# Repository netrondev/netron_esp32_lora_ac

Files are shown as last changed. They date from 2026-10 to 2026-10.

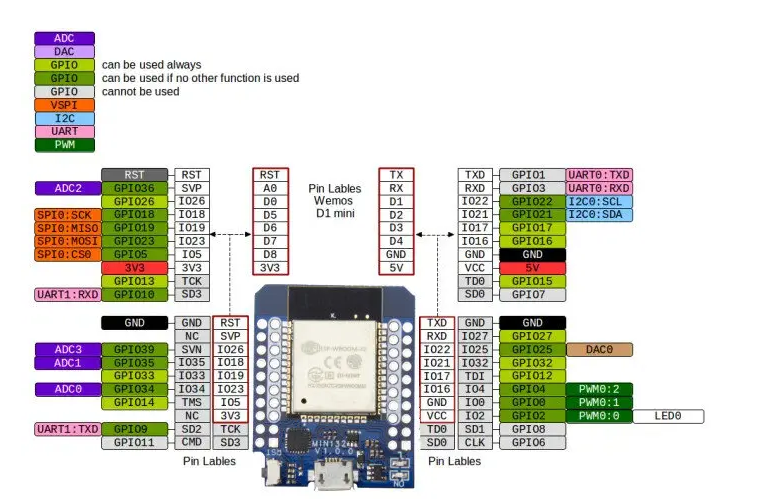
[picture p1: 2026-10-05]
images/esp32-mini-pinout.png

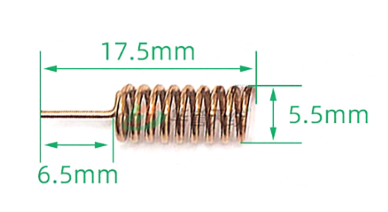
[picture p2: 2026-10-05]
hardware/antenna_868.png

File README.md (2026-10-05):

# ESP32 LoRaWAN AC current monitor

A mains current monitor built on an ESP32 and an SX1262 radio. It measures AC
current through an ACS712 hall-effect sensor and reports it over LoRaWAN as an
OTAA Class A device. The repo also includes a small network server so you can
receive the reports and configure devices remotely, plus the KiCad hardware.

Everything is written in Rust except the payload codec, which is plain
JavaScript so it can be pasted into ChirpStack, The Things Network or Node-RED.

## How the pieces fit together

```
ACS712 current sensor
  └─ ESP32 + SX1262           firmware/           OTAA Class A device
       ~ 868.1 MHz SF7 ~
  └─ Milesight UG63 gateway                       Semtech UDP packet forwarder
       └─ software/lorans                         network server: joins, keys,
                                                  uplink decode, downlink queue
```

The gateway's own network server is **not** used. It has no usable downlink
route: there's no HTTP endpoint, and its MQTT application forwarder reboots the
gateway. Without downlinks there's no remote configuration. So the gateway runs
as a plain packet forwarder, and `software/lorans` does the network server's
job. `software/lorans/README.md` has the details.

Any gateway that speaks the Semtech UDP protocol should work in place of the
UG63. Alternatively, the devices can join a standard network server such as
ChirpStack, using the codec in `software/loradecode`.

| Directory | What it is |
|---|---|
| `firmware/` | ESP32 firmware. Measures current, joins by OTAA, reports aggregated min/avg/max, applies configuration downlinks |
| `software/lorans/` | Network server. Run this to receive uplinks and send commands |
| `software/loradecode/` | JavaScript payload decoder and command encoder for ChirpStack, TTN or Node-RED |
| `software/milesight_d4/` | Milesight gateway HTTP client: status, device list, forwarder mode, payload decode/encode |
| `software/loramqtt/` | Minimal MQTT broker, kept for diagnosing the gateway's MQTT forwarding |
| `docs/PROTOCOL.md` | Uplink channel map and downlink command set |
| `diagram/` | System overview: power supply, sensing, MCU and radio |
| `hardware/` | KiCad schematics, PCBs and JLCPCB fabrication outputs |
| `scripts/` | Build, flash and monitor helpers |

## Hardware

- **MCU:** ESP32 Mini32 (Wemos D1 Mini ESP32 form factor)
- **Radio:** Ai-Thinker Ra-01SH (SX1262), 868 MHz
- **Sensor:** ACS712-20A on GPIO34 through a voltage divider. RMS current is
  computed over one 50 Hz cycle of oversampled ADC readings
- **Power:** MB10S bridge rectifier into a BP2525 non-isolated buck, 5 V from
  230 V mains

| SX1262 | ESP32 |
|---|---|
| NSS | GPIO5 |
| RESET | GPIO27 |
| DIO1 | GPIO26 |
| SCK | GPIO18 |
| MISO | GPIO19 |
| MOSI | GPIO23 |

BUSY isn't wired to the ESP32. The driver waits a fixed settling time after
each command instead, and detects TxDone/RxDone from DIO1. The status LED is
on GPIO2.

> **Warning:** the power supply is non-isolated, so the whole board sits at
> mains potential. Don't touch it or connect USB while it's powered from
> mains.

## Device identity and keys

| | |
|---|---|
| DevEUI | Derived from the ESP32's MAC: `OUI FF FE NIC` |
| JoinEUI | `0000000000000000` |
| AppKey | The DevEUI repeated, e.g. `E08CFEFFFE34C3AC` → `E08CFEFFFE34C3ACE08CFEFFFE34C3AC` |

This follows the Milesight convention, so a device can be onboarded from
nothing but its join request. It also means **the AppKey is not a secret**.
That's fine for a private network on a private gateway. If you need real
over-the-air security, give each device a random AppKey. `docs/PROTOCOL.md`
covers this, along with the payload format.

## Getting started

### Toolchain

The ESP32 needs Rust's Xtensa toolchain. Install it with
[espup](https://github.com/esp-rs/espup), which writes `~/export-esp.sh`, then
install `espflash`:

```bash
cargo install espup espflash
espup install
```

Alternatively, build inside Docker with the image in `firmware/`. `scripts/build.sh`
and `scripts/flash.sh` use it:

```bash
docker build -t esp32-rust firmware/
```

### Flash and monitor a device

The scripts find the serial port automatically, or you can pass it explicitly:

```bash
./scripts/flash_native.sh            # host toolchain: build, flash, print the MAC
./scripts/flash.sh /dev/ttyUSB0      # same, building in Docker
./scripts/monitor.sh                 # serial monitor in Docker (CTRL+R resets, CTRL+C exits)
```

### Run the network server

Point the gateway's packet forwarder at this host on UDP port 1700, then start
the network server:

```bash
cargo run --manifest-path software/lorans/Cargo.toml
```

It accepts joins, decodes uplinks and queues downlinks. Commands go to a
control socket on `127.0.0.1:7788`. A queued downlink is sent in the receive
window after the device's next uplink. Intervals are in seconds:

```bash
echo 'downlink E08CFEFFFE34C3AC report=60 sample=5 jitter=10' | nc -q1 127.0.0.1 7788
echo 'list' | nc -q1 127.0.0.1 7788
```

### Milesight gateway

Copy `software/milesight_d4/config.json.example` to `config.json` and add the
gateway's address and login. Then:

```bash
cargo run --manifest-path software/milesight_d4/Cargo.toml -- status
cargo run --manifest-path software/milesight_d4/Cargo.toml -- set-forwarder semtech 192.168.1.100
```

## Firmware behaviour

- Joins by OTAA, retrying with exponential backoff
- Samples current every `sample` seconds and accumulates min/avg/max
- Sends one confirmed, aggregated report every `report` seconds, offset by a
  random ± `jitter` seconds so devices don't collide. An unacknowledged
  report is retried once
- Re-joins if the network stops acknowledging
- Applies configuration downlinks (intervals, jitter, reboot) and echoes each
  applied setting back as confirmation
- Keeps cumulative energy (mAh), frame counters, the join nonce and its
  configuration in flash across power cycles

### LED

| Pattern | Meaning |
|---|---|
| Short blink every ~0.5 s | Not joined yet, trying to join |
| Short blink per sample | Joined and measuring normally |
| Rapid triple blink | ADC error: sensor disconnected, or the reading saturated at 0 or 4095 |

## Troubleshooting

- **`xtensa-esp32-elf-gcc not found`:** run `source ~/export-esp.sh` first.
- **Permission denied on the serial port:** add yourself to the `dialout`
  group, or `sudo chmod 666 /dev/ttyUSB0`.
- **Device not found:** check `ls /dev/ttyUSB* /dev/ttyACM*`.
- **espflash asks for a chip or port inside Docker:** pass
  `--chip esp32 -p <port>` explicitly.
- **Flashing fails to connect:** hold BOOT while flashing, and release it
  after "Connecting...".

## License

Licensed under either of

- Apache License, Version 2.0 ([LICENSE-APACHE](LICENSE-APACHE))
- MIT license ([LICENSE-MIT](LICENSE-MIT))

at your option.

Unless you explicitly state otherwise, any contribution intentionally submitted
for inclusion in this work by you, as defined in the Apache-2.0 license, shall
be dual licensed as above, without any additional terms or conditions.

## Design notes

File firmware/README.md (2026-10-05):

# Firmware

Bare-metal (`no_std`) Rust firmware for the ESP32. The main binary measures AC
current and reports it over LoRaWAN. The [root README](../README.md) covers
the hardware, pinout, toolchain setup and LED patterns.

## Building

The toolchain is pinned to the `esp` channel by `rust-toolchain.toml`, so run
Cargo from this directory, not with `--manifest-path`:

```bash
source ~/export-esp.sh
cargo build -p app --release
espflash flash --chip esp32 -p /dev/ttyUSB0 --monitor target/xtensa-esp32-none-elf/release/app
```

`../scripts/flash_native.sh` does the same and finds the port automatically.
To build in Docker instead, run `docker build -t esp32-rust .` here, then use
`../scripts/flash.sh`.

To build one of the bench tests below, name it with `--bin`. It lands at
`target/xtensa-esp32-none-elf/release/<name>`:

```bash
cargo build -p app --release --bin otaa_test
```

## Binaries

Binaries are declared explicitly in `app/Cargo.toml` (`autobins = false`).

| Binary | Purpose |
|---|---|
| `app` | Production firmware (`src/bin/main.rs`) |
| `otaa_test` | Joins, then sends a confirmed uplink every 30 s and prints what comes back. Use it to check joins and downlinks on a new gateway |
| `ra01sh_test` | Checks SPI communication with the SX1262 |
| `rx_test` | Listens for raw LoRa packets and prints them |
| `adc_test` | ADC sampling with heavy oversampling |
| `acs712_current_test` | Current measurement on its own, without the radio |

## Source layout

| Module | What it does |
|---|---|
| `lora/sx1262.rs` | SX1262 driver. `sx1278.rs` is the driver for the earlier 433 MHz SX1278 boards |
| `lorawan.rs` | LoRaWAN 1.0.x: join, MIC, encryption, uplink/downlink framing |
| `mac.rs` | Class A MAC layer: join, transmit and the two receive windows |
| `packet.rs` | Uplink payload encoding and the min/avg/max sample accumulator |
| `config.rs` | Device configuration and downlink command parsing |
| `session_store.rs` | Persists the LoRaWAN session and configuration in flash |
| `flash_storage.rs` | Wear-levelled flash storage for the cumulative energy total |

The payload format and command set are specified in
[`docs/PROTOCOL.md`](../docs/PROTOCOL.md).

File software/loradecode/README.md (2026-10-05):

# Payload codec for the ESP32 power monitors

`decode.js` turns device uplinks into readable JSON and turns configuration
settings into downlink bytes. No dependencies, ES5 only, so it can be pasted
straight into ChirpStack, The Things Network or Node-RED.

The device uses **FPort 85** in both directions.

## Installing it on a network server

Paste the whole file into the codec field. It provides every entry point the
common platforms look for, so the same file works unchanged:

| Platform | Uses |
|---|---|
| ChirpStack v4 | `decodeUplink(input)` / `encodeDownlink(input)` |
| ChirpStack v3 | `Decode(fPort, bytes)` / `Encode(fPort, obj)` |
| The Things Network | `Decoder(bytes, port)` / `Encoder(obj, port)` |
| Node.js | `require("./decode.js")` |

## What an uplink decodes to

A periodic report:

```json
{
  "current_avg": 12,
  "current_min": 8,
  "current_max": 19,
  "cumulative_charge": 56,
  "sample_count": 4
}
```

Currents are **milliamps**, `cumulative_charge` is **milliamp-hours** since the
device was first powered on, and `sample_count` is how many measurements went
into this report.

`sample_count` is the field to watch if something looks wrong. It should be
roughly `report_interval / sample_interval` — a count of 0 means no measurement
completed, and a count well below that means the device is not keeping up.

After every join the device sends its identity instead:

```json
{
  "power_on": true,
  "protocol_version": 1,
  "hardware_version": "v1.0",
  "firmware_version": "v0.7",
  "lorawan_class": "A",
  "sn": "E08CFEFFFE34C3AC"
}
```

`sn` is the DevEUI.

An `undecoded_at` field means decoding stopped at that byte offset because it
met a record it did not recognise — usually a firmware newer than this decoder.
Everything before that offset is still valid.

## Sending configuration

All intervals are in **seconds**.

```js
encodeDownlink({ data: { report_interval: 300 } })   // report every 5 minutes
encodeDownlink({ data: { sample_interval: 5 } })     // measure every 5 seconds
encodeDownlink({ data: { jitter: 10 } })             // spread reports by ±10 s
encodeDownlink({ data: { reboot: true } })
```

Several settings can go in one downlink:

```js
encodeDownlink({ data: { report_interval: 60, sample_interval: 5, jitter: 10 } })
```

| Setting | Range | What it does |
|---|---|---|
| `report_interval` | 10–65535 s | How often the device transmits |
| `sample_interval` | 1–3600 s | How often it measures. Samples are collected and summarised into one report — they are not sent individually |
| `jitter` | 0–600 s | Spreads transmissions out. Devices powered on together would otherwise transmit in lockstep and collide on air. It does not change the average interval |
| `reboot` | — | Restarts the device. Configuration and the energy total survive |

Out-of-range values throw rather than being sent, because the device would
silently reject them.

### When it takes effect

These are Class A devices: they only listen briefly after transmitting. A
downlink therefore waits until the device's next report — **up to a full report
interval**. Queue it and be patient rather than sending it repeatedly.

The device **echoes back every command it accepted** in its next uplink, and
that echo is the acknowledgement:

```json
{ "report_interval": 300, "sample_interval": 5 }
```

If the echo does not arrive, the command either fell outside its range or never
reached the device — send it again.

A reboot is echoed *before* the device restarts, so `{"reboot": true}` coming
back means it is about to happen. The device rejoins afterwards and sends a
fresh identity packet.

## Worked example

`example.js` runs the whole cycle against payloads captured from a real device,
so it demonstrates the flow with no hardware attached:

```bash
node example.js
```

It builds a downlink, tracks it as unconfirmed, feeds in the uplinks that
follow, recognises the echo that confirms it, and shows what to do about a
command whose echo never arrives. `classifyUplink` and `PendingCommands` are
the two pieces worth lifting into your own integration.

## Command line

```bash
node decode.js 03980c00049808000598130006c83800000007040400
node decode.js A5gMAASYCAAFmBMABsg4AAAABwQEAA==
node decode.js encode report=60 sample=5 jitter=10
node decode.js encode reboot
```

`encode` prints the payload as hex and base64, ready to paste into whatever
queues the downlink.

## Wire format

`docs/PROTOCOL.md` has the byte-level detail — the channel map, the command
table, and the activation parameters.

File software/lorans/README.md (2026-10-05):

# lorans — network server for the ESP32 power monitors

A minimal LoRaWAN 1.0.x network server. The gateway runs as a plain Semtech UDP
packet forwarder and this handles joins, session keys, uplink decoding and the
downlink queue.

## Why this exists

The gateway has a perfectly good built-in network server, and we are not using
it, for one reason: **it has no way to send a downlink that works.**

- There is no HTTP downlink endpoint. The web UI exposes `/ns/device*`,
  `/ns/application*`, `/ns/packets`, `/ns/traffic` and `/packet/*`, and nothing
  that queues a downlink.
- Its only downlink path is the application MQTT forwarder, and enabling that
  **reboots the gateway**. Observed on UG63-868M firmware 64.0.0.4-r1: the
  gateway connects to the broker, subscribes to `<app>/downlink` and
  `<app>/request`, resets the connection, and reboots — `run_time` returns to
  zero — within about twenty seconds, having exchanged no data. Then it repeats.

Without downlinks there is no remote configuration, so the network server moved
to this side, where we control the whole exchange.

## Running it

```bash
cargo run -p lorans           # or: cargo run --manifest-path software/lorans/Cargo.toml
```

It listens on UDP 1700 for the packet forwarder and TCP 127.0.0.1:7788 for
control. Sessions are persisted to `sessions.json` (override with
`LORANS_STATE`).

**Keep that state file.** If the server forgets a session, the device carries
on using keys we no longer hold, every uplink fails its MIC check, and — having
no session — we cannot even tell it to rejoin. The firmware recovers on its own
after four unacknowledged reports, but that is a fallback, not a plan.

## Pointing the gateway at it

```bash
cd software/milesight_d4
cargo run -- set-forwarder semtech 192.168.1.100 1700   # this host
cargo run -- set-forwarder embedded                      # revert to the gateway's own NS
```

While in Semtech mode the gateway's own device list, packet log and
applications go unused — devices join *here*, and `milesight_d4 packets` will
not show them.

## Sending commands

Intervals are in seconds. See `docs/PROTOCOL.md` for the wire format.

```bash
echo 'list' | nc -q1 127.0.0.1 7788
echo 'downlink E08CFEFFFE34C3AC report=300' | nc -q1 127.0.0.1 7788
echo 'downlink E08CFEFFFE34C3AC report=60 sample=5 jitter=10' | nc -q1 127.0.0.1 7788
echo 'downlink E08CFEFFFE34C3AC reboot' | nc -q1 127.0.0.1 7788
echo 'downlink E08CFEFFFE34C3AC FF032C01' | nc -q1 127.0.0.1 7788   # raw hex
```

A Class A device only listens in the two windows after one of its own uplinks,
so a queued command goes out after the device's next report — up to a full
report interval away. One downlink is delivered per uplink; the rest stay
queued, with the frame-pending bit set.

The device echoes every command it accepted in its next uplink, and that echo
is the acknowledgement. A command that comes back took effect; one that does
not was either out of range and rejected, or never arrived — a queued downlink
is transmitted once and not retried, so if no echo appears, queue it again.

## What it does not do

One channel (868.1 SF7), RX1 only, no ADR, no MAC commands, no class B or C,
and it accepts exactly one AppKey convention — `DevEUI‖DevEUI`, which is what
our firmware uses. Anything else on air is logged and ignored.

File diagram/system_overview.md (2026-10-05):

# System overview

```mermaid
flowchart TB
    subgraph AC["AC Mains Input (230V AC)"]
        MAINS["230V AC\nMains"]
    end

    subgraph PSU["Power Supply (PCB)"]
        BRIDGE["MB10S\nBridge Rectifier\n~325V DC"]
        BUCK["BP2525D\nNon-isolated Buck\n5V / 300mA"]
        BRIDGE --> BUCK
    end

    subgraph SENSE["Current Sensing"]
        ACS["ACS712-20A\nHall-Effect Sensor\n±20A AC/DC\nAnalog out @ 185mV/A"]
    end

    subgraph MCU["Microcontroller — ESP32 Mini (Wemos D1 Mini32)"]
        ADC["ADC GPIO34\n(ACS712 output)"]
        FW["Rust Firmware\n• RMS current calc\n• min/avg/max per report\n• Cumulative energy (flash)\n• OTAA Class A, remote config"]
        ADC --> FW
    end

    subgraph RADIO["LoRa Radio"]
        LORA["Ra-01SH\nSX1262\n868 MHz\nSPI interface"]
        ANT["868 MHz\nAntenna"]
        LORA --> ANT
    end

    subgraph GW["LoRa Gateway"]
        GWDEV["Milesight UG63\nSemtech UDP\npacket forwarder"]
    end

    subgraph SERVER["Server"]
        NS["lorans\nnetwork server\njoins, keys, decode,\ndownlink queue"]
    end

    %% Power flow
    MAINS -->|"AC In"| BRIDGE
    MAINS -->|"AC through sensor"| ACS
    BUCK -->|"5V regulated"| MCU
    BUCK -->|"5V regulated"| RADIO

    %% Sensor to MCU
    ACS -->|"Analog voltage\n(GPIO34)"| ADC

    %% MCU to LoRa (SPI)
    FW -->|"SPI\nGPIO18/19/23/5\nRST GPIO27\nDIO1 GPIO26"| LORA

    %% RF link
    ANT <-.->|"LoRaWAN 868MHz\nuplinks + downlinks"| GWDEV

    %% Gateway to server
    GWDEV <-->|"UDP 1700"| NS

    %% Styles
    classDef power fill:#ff9f43,stroke:#e17055,color:#000
    classDef mcu fill:#0984e3,stroke:#74b9ff,color:#fff
    classDef radio fill:#6c5ce7,stroke:#a29bfe,color:#fff
    classDef server fill:#00b894,stroke:#55efc4,color:#000
    classDef sense fill:#fdcb6e,stroke:#e17055,color:#000

    class BRIDGE,BUCK power
    class ADC,FW mcu
    class LORA,ANT radio
    class NS server
    class ACS sense
```

## Data flow

| Stage | Component | Protocol |
|---|---|---|
| AC sense | ACS712-20A → GPIO34 | Analog voltage |
| Compute | ESP32 (Rust firmware) | Internal |
| Transmit | SX1262 Ra-01SH | LoRaWAN 868 MHz, FPort 85 |
| Forward | Milesight UG63 gateway | Semtech UDP |
| Decode and configure | `software/lorans` | See [`docs/PROTOCOL.md`](../docs/PROTOCOL.md) |

## Power budget (5V rail)

| Component | Current |
|---|---|
| ESP32 (no WiFi/BLE) | ~80 mA |
| SX1262 TX peak | ~120 mA |
| ACS712 | ~10 mA |
| **Total peak** | **~200 mA** |
| BP2525D capacity | 300 mA cont / 500 mA pulse |

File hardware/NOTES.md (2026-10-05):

ESP32 Board
===================

https://api.riot-os.org/group__boards__esp32__mh-et-live-minikit.html

LORA
===================

Switch from 433 to 868

Pick: `Ra-01SH`

Basic LoRa Modules (no MCU, SPI-controlled)
  ┌────────────────┬────────┬─────────────┬──────────────────┬─────────────────────────────┐
  │     Model      │  Chip  │  Frequency  │     Antenna      │            Notes            │
  ├────────────────┼────────┼─────────────┼──────────────────┼─────────────────────────────┤
  │ Ra-01          │ SX1278 │ 410–525 MHz │ Solder pad       │ Basic, spring antenna       │
  ├────────────────┼────────┼─────────────┼──────────────────┼─────────────────────────────┤
  │ Ra-01H         │ SX1278 │ 803–930 MHz │ Solder pad       │ High-freq variant of Ra-01  │
  ├────────────────┼────────┼─────────────┼──────────────────┼─────────────────────────────┤
  │ Ra-01S         │ SX1262 │ 410–525 MHz │ Half-hole / IPEX │ Upgraded chip vs Ra-01      │
  ├────────────────┼────────┼─────────────┼──────────────────┼─────────────────────────────┤
  │ Ra-01SH        │ SX1262 │ 803–930 MHz │ Half-hole / IPEX │ High-freq SX1262            │
  ├────────────────┼────────┼─────────────┼──────────────────┼─────────────────────────────┤
  │ Ra-01SC        │ SX1262 │ 410–525 MHz │ Half-hole / IPEX │ ~4.7 km range               │
  ├────────────────┼────────┼─────────────┼──────────────────┼─────────────────────────────┤
  │ Ra-01SCH       │ SX1262 │ 803–930 MHz │ Half-hole / IPEX │ High-freq SC variant        │
  ├────────────────┼────────┼─────────────┼──────────────────┼─────────────────────────────┤
  │ Ra-02          │ SX1278 │ 410–525 MHz │ IPEX             │ ~4 km range, popular module │
  ├────────────────┼────────┼─────────────┼──────────────────┼─────────────────────────────┤
  │ Ra-03SCH       │ SX1262 │ 803–930 MHz │ ?                │ Newer variant               │
  ├────────────────┼────────┼─────────────┼──────────────────┼─────────────────────────────┤
  │ Ra-05 / Ra-05U │ —      │ —           │ —                │ Less documented             │
  └────────────────┴────────┴─────────────┴──────────────────┴─────────────────────────────┘

 Key Differences

  - "H" suffix = High frequency (803–930 MHz, i.e. 868/915 MHz bands for EU/US/AU). Without H = low frequency (410–525 MHz, i.e. 433 MHz band for Asia).
  - "S" suffix = SX1262 chip upgrade (better sensitivity, lower power vs SX1278).
  - "C" suffix = improved range variant.
  - Ra-01/02 series = pure RF modules, no MCU — you drive them over SPI from your own MCU (ESP32, STM32, etc.).
  - Ra-08/08H = have a built-in ARM Cortex-M4 MCU + LoRaWAN stack. Can be used standalone or controlled via AT commands over UART. 128 KB flash, 16 KB SRAM,
  peripherals (UART, SPI, I2C, ADC, DAC, PWM, GPIO).
  - Ra-09 = uses STM32WLE5 (ST's integrated LoRa SoC) instead of ASR6601.

Breakout board for validation: https://make.net.za/product/3me0700/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

https://www.semtech.com/products/wireless-rf/lora-connect/sx1262

## Lora Antenna

17.5mm 5.5mm 6.5mm

https://make.net.za/product/3me0850/

POWER SUPPLY
=================

For prototyping/low volume: Use the HLK-PM01 module (easier, safer, pre-certified)

smallest LS01-K3B05SS

For production (>1000 units): Consider the BP2522 IC approach like Shelly (lower BOM cost, but requires expertise)

  Alternative IC: The BP2836D is another Bright Power chip used in similar applications with higher power output capability..

AC supply
==========
References:
- https://www.youtube.com/watch?v=_MwQRQSlA0k

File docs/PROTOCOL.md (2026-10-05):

# ESP32 power monitor — LoRaWAN protocol

The contract between the firmware, the decoders in `software/`, and any
platform consuming the data. Anything here that changes has to change in all
three places.

## Activation

The devices are **OTAA, Class A, LoRaWAN 1.0.x**, on EU868. There is no ABP
support.

| Value | How it is derived |
|---|---|
| DevEUI | The ESP32 MAC expanded to an EUI-64: `MAC[0..3] + FF FE + MAC[3..6]`. A device with MAC `E0:8C:FE:34:C3:AC` has DevEUI `E08CFEFFFE34C3AC`. |
| JoinEUI (AppEUI) | `0000000000000000`. This is a private network and we hold no IEEE-assigned JoinEUI block; the network server identifies devices by DevEUI. |
| AppKey | The DevEUI repeated: `E08CFEFFFE34C3AC` → `E08CFEFFFE34C3ACE08CFEFFFE34C3AC`. |

The AppKey convention is Milesight's own, and it is what makes zero-touch
onboarding possible: a join request carries the DevEUI in clear, so the
gateway tooling can derive the key, verify the join MIC, and register the
device without anyone typing a key in. It also means **the AppKey is not a
secret** — anyone who can hear a join request can derive it. That is an
accepted trade for a private network on a private gateway; if these devices
ever join a network where that matters, move to random per-device keys
provisioned at flash time.

The join nonce is persisted in flash and incremented before every attempt,
including attempts that fail. Network servers reject a repeated nonce.

**FPort 85** is used for uplinks and downlinks alike.

## Frame format

Payloads are a flat sequence of records, following the Milesight convention:

```
channel(1) | type(1) | value(N)   channel(1) | type(1) | value(N)   ...
```

Values are **little-endian**. There is **no length byte on the wire** — the
length of each record is implied by its channel/type pair, so a decoder must
know every pair it might see. An unrecognised pair means the rest of the frame
cannot be located and decoding stops there.

## Uplinks

### Device information

Sent once after every successful join.

| Item | Bytes | Notes |
|---|---|---|
| Power on | `ff 0b ff` | |
| Protocol version | `ff 01 01` | This document's version |
| Hardware version | `ff 09 <major> <minor>` | |
| Firmware version | `ff 0a <major> <minor>` | From the crate version |
| Device class | `ff 0f 00` | Class A |
| Serial number | `ff 16 <8 bytes>` | The DevEUI |

Example, from a v0.7.0 device:

```
ff0bff ff0101 ff090100 ff0a0007 ff0f00 ff16e08cfefffe34c3ac
```

### Periodic report

One report per heartbeat, summarising every sample taken since the last one.

| Item | Bytes | Units |
|---|---|---|
| Current, average | `03 98 <u16>` | mA |
| Current, minimum | `04 98 <u16>` | mA |
| Current, maximum | `05 98 <u16>` | mA |
| Cumulative charge | `06 c8 <u32>` | mAh, since first power-on |
| Sample count | `07 04 <u16>` | samples in this window |

Example — 12 mA average, 8 mA min, 19 mA max, 56 mAh total, 4 samples:

```
03980c00 04980800 05981300 06c838000000 07040400
```

Reports are sent **confirmed**. If the network does not acknowledge, the frame
is retransmitted exactly once, reusing its frame counter, and then dropped.

`sample_count` is worth watching: a count of 0 means no measurement completed
in the window, and a count far from `report_interval / sample_interval` means
the device is not keeping up with the configured cadence.

## Downlinks

Sent on FPort 85. A Class A device only listens in the two windows following
one of its own uplinks, so a downlink is queued at the network server and
delivered after the device's next report — with a 60-second report interval,
expect up to a minute of latency.

| Command | Bytes | Range |
|---|---|---|
| Reboot | `ff 10 ff` | — |
| Sample interval | `ff 02 <u16>` | 1–3600 s |
| Report interval | `ff 03 <u16>` | 10–65535 s |
| Heartbeat jitter | `ff 04 <u16>` | 0–600 s |
| Report interval, in minutes | `ff 8e 00 <u16>` | 1–1092 min |

Several commands may be concatenated into one frame.

`ff 8e` is an alias accepted for compatibility with platforms built against
Milesight's newer sensors, which express this interval in minutes. It is
converted to seconds on arrival and echoed back in the canonical `ff 03`
seconds form, so what comes back always says what the device is actually
doing.

**Jitter** spreads transmissions out: the next report is scheduled at
`report_interval ± jitter`, redrawn each time. Devices powered up together
would otherwise transmit in lockstep and collide on air indefinitely. It is
not a delay — the average interval is unchanged.

### Echoes

Every accepted command is echoed back on channel `ff` with the same type and
value in the next uplink. **The echo is the acknowledgement.** A command that
is out of range is rejected and not echoed, so a value that comes back is one
that took effect.

Setting the report interval to 300 s:

```
downlink:  ff 03 2c 01
next uplink contains: ff 03 2c 01
```

A reboot is echoed *before* the device resets, so `ff 10 ff` coming back means
the reboot is about to happen, not that it has happened. The device rejoins
afterwards and sends a fresh device information packet.

## Working with payloads

```bash
cd software/milesight_d4

# Decode an uplink (hex or base64), e.g. from `milesight_d4 packets`
cargo run -- decode 03980c00049808000598130006c838000000 07040400

# Encode downlink commands
cargo run -- encode report=300 sample=5
cargo run -- encode reboot
```

`software/loradecode/decode.js` is the JavaScript equivalent, for use as a network
server codec, and mirrors `software/milesight_d4/src/tlv.rs`.

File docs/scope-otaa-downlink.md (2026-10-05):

# Scope of work — secure activation and remote configuration

Moving the power monitors from a single shared key set and compiled-in timings
onto per-device secure activation, and making them configurable over the air so
a unit in the field can be adjusted without being collected and reflashed.

- Secure per-device activation (OTAA), replacing the shared keys used across
  the whole fleet.
- Remote configuration by downlink: reporting interval, measurement interval,
  transmission spread and remote reboot, all in seconds.
- Measurement separated from transmission — readings are taken at the
  measurement interval and combined into one report per reporting interval,
  sent as average, minimum, maximum and reading count.
- Acknowledged transmissions, with automatic re-join if the network stops
  responding, and confirmation echoed back for every setting applied.
- Settings, cumulative energy total and network session retained across power
  cycles and reboots.
- New payload format following the conventions of the Milesight sensors
  already in use.
- Corrected a fault in the radio driver that stalled the device after each
  transmission and made downlink reception impossible.
- Established that the gateway cannot deliver downlinks — no HTTP route, and
  its MQTT forwarding reboots the gateway (UG63 firmware 64.0.0.4-r1) — and
  built a replacement network server alongside it to handle joins, decoding
  and the queue of pending commands.
- JavaScript decoder, command encoder and worked example for integration, plus
  written specification of the message format and command set.
- Verified end to end on live hardware.

Not included: the two units in the field still run the previous firmware and
need reflashing over USB before they can join under the new scheme.

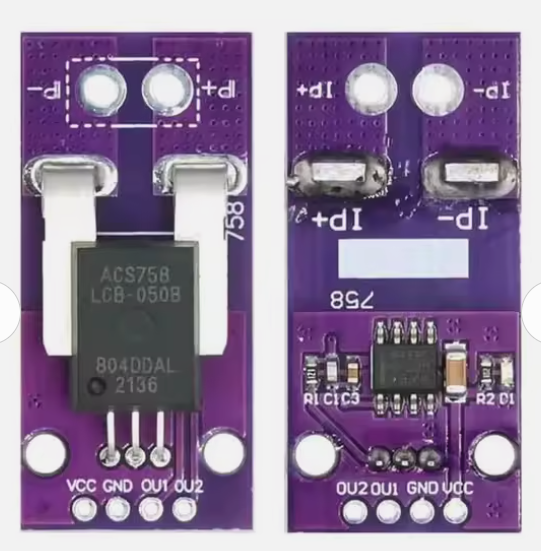
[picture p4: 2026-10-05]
images/acs758-board.png

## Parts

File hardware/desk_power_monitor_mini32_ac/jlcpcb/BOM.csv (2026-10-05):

Comment | Designator | Footprint | LCSC Part #
100nF | C1 | C_0805_2012Metric | C49678
1nF | C2 | C_0805_2012Metric | C62774
LED | D1 | D_0805_2012Metric | C2297
HLK-PM01 | PS1 | Converter_ACDC_Hi-Link_HLK-PMxx
1K | R3 | R_0805_2012Metric | C17513
10k | R1,R2 | R_0805_2012Metric | C17414
ACS712ELCTR-20A | U2 | SOIC-8_3.9x4.9mm_P1.27mm | C10681

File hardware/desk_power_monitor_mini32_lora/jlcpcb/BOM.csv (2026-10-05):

Comment | Designator | Footprint | LCSC Part #
RA-01SH | U1 | WIRELM-SMD_RA-01SH | C2764087
0R | C1 | C_0805_2012Metric | C17477
0R | L1 | L_0805_2012Metric | C17477

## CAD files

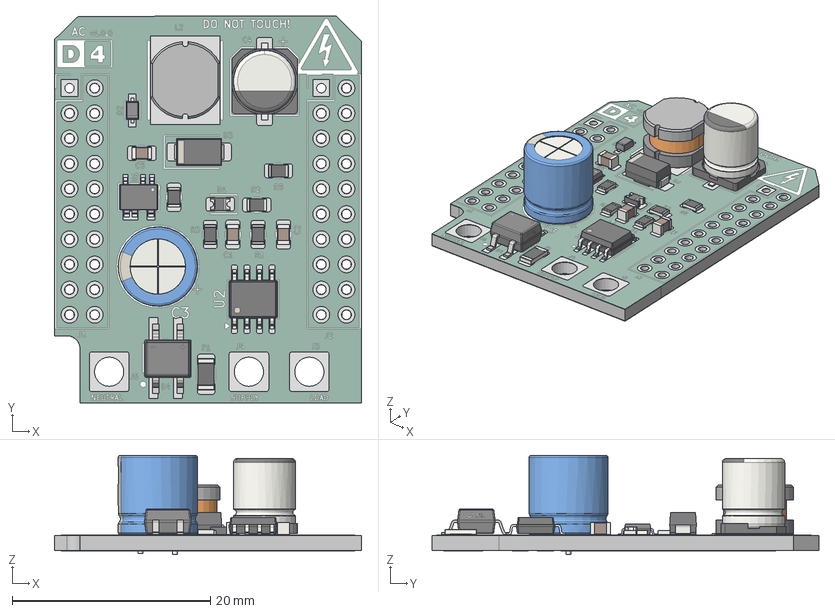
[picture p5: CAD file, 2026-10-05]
hardware/desk_power_monitor_mini32_ac/desk_power_monitor_mini32_ac_full.step
31.0 x 39.0 x 10.0 mm
IND-SMD_L7.8-W7.0-A
CP_Elec_6.3x7.7
D_0805_2012Metric
MBS_L4.7-W4.0-H2.5-LS7.0
R_0805_2012Metric x 5
C_0805_2012Metric x 3
CP_Radial_D8.0mm_P3.50mm
SOD-323_L1.8-W1.3-LS2.5-RD-1
SOIC-8_3.9x4.9mm_P1.27mm
SOT33-5A_L3.9-W2.6-P0.90-BP2525D
D_SMA
Fuse_1206_3216Metric
desk_power_monitor_mini32_ac_copper
desk_power_monitor_mini32_ac_pad
desk_power_monitor_mini32_ac_via
desk_power_monitor_mini32_ac_silkscreen
desk_power_monitor_mini32_ac_soldermask
desk_power_monitor_mini32_ac_PCB

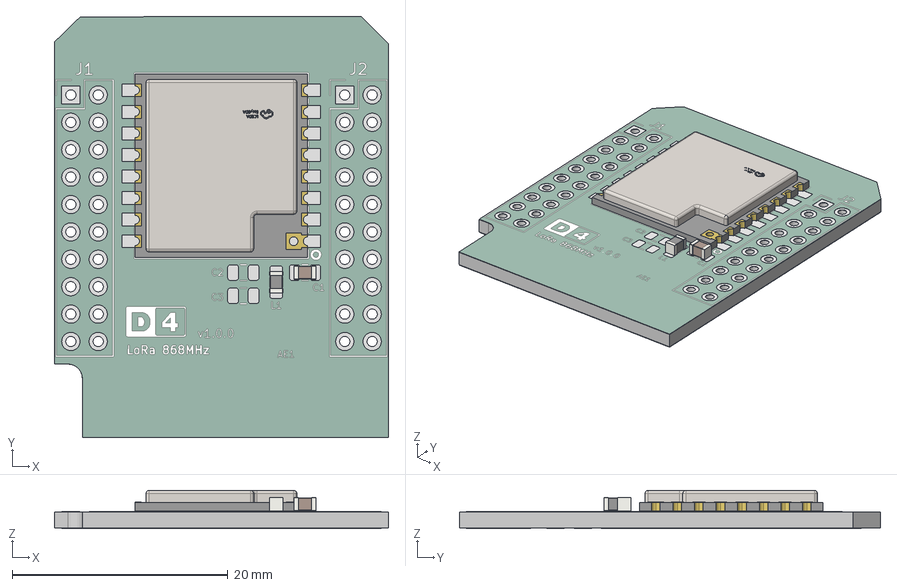
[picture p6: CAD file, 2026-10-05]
hardware/desk_power_monitor_mini32_lora/desk_power_monitor_mini32_lora.step
31.0 x 39.0 x 3.55 mm
L_0805_2012Metric
C_0805_2012Metric
WIRELM-SMD_RA-01SH
desk_power_monitor_mini32_lora_copper
desk_power_monitor_mini32_lora_pad
desk_power_monitor_mini32_lora_via
desk_power_monitor_mini32_lora_silkscreen
desk_power_monitor_mini32_lora_soldermask
desk_power_monitor_mini32_lora_PCB

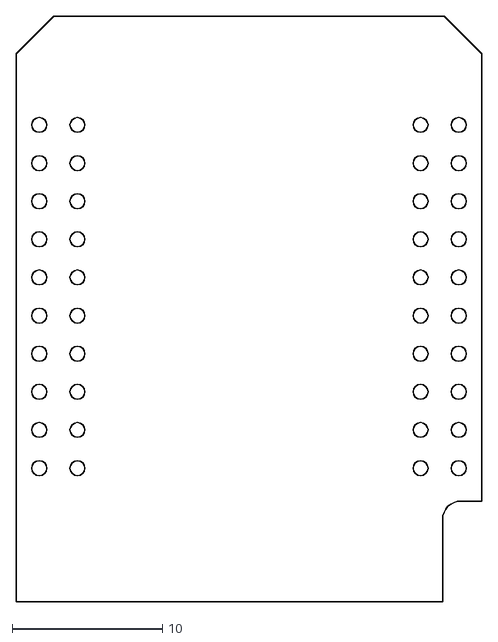
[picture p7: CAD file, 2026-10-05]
hardware/MINI32 footprint.dxf
31.0 x 39.0

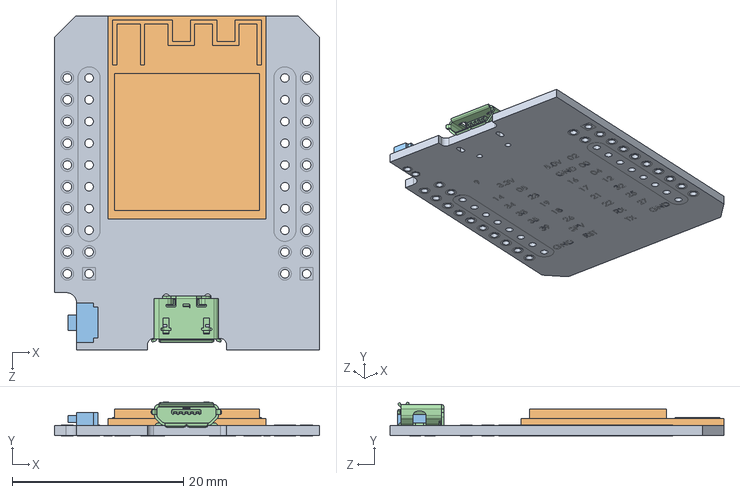
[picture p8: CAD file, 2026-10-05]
hardware/wemos-mini32-esp32/esp32-wemos-d1-mini.step
31.0 x 3.92 x 39.0 mm

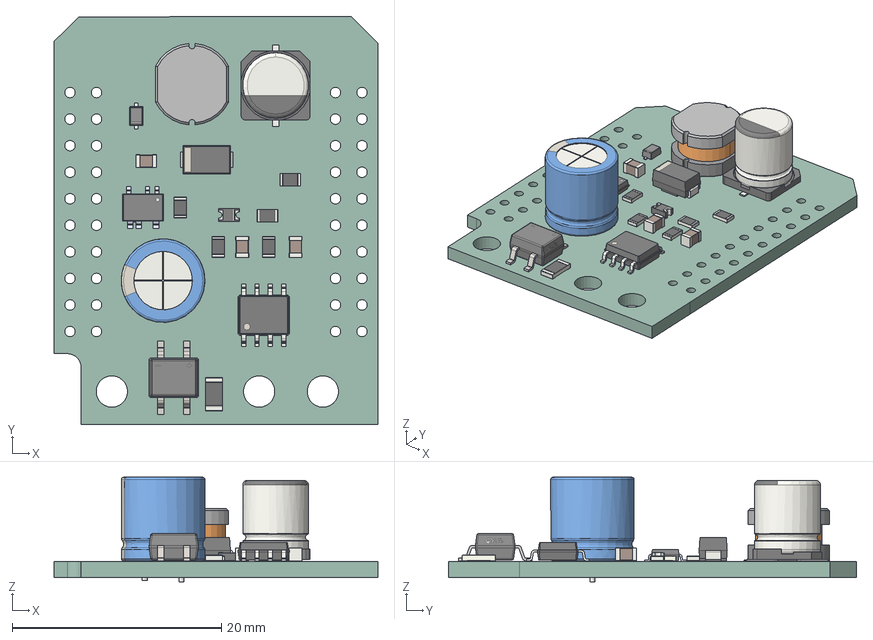
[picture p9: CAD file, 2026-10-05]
hardware/desk_power_monitor_mini32_ac/desk_power_monitor_mini32_ac.step
31.0 x 39.0 x 10.0 mm
IND-SMD_L7.8-W7.0-A
CP_Elec_6.3x7.7
D_0805_2012Metric
MBS_L4.7-W4.0-H2.5-LS7.0
R_0805_2012Metric x 5
C_0805_2012Metric x 3
CP_Radial_D8.0mm_P3.50mm
SOD-323_L1.8-W1.3-LS2.5-RD-1
SOIC-8_3.9x4.9mm_P1.27mm
SOT33-5A_L3.9-W2.6-P0.90-BP2525D
D_SMA
Fuse_1206_3216Metric
desk_power_monitor_mini32_ac_PCB

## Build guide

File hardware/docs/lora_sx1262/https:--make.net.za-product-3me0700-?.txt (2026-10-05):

https://make.net.za/product/3me0700/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

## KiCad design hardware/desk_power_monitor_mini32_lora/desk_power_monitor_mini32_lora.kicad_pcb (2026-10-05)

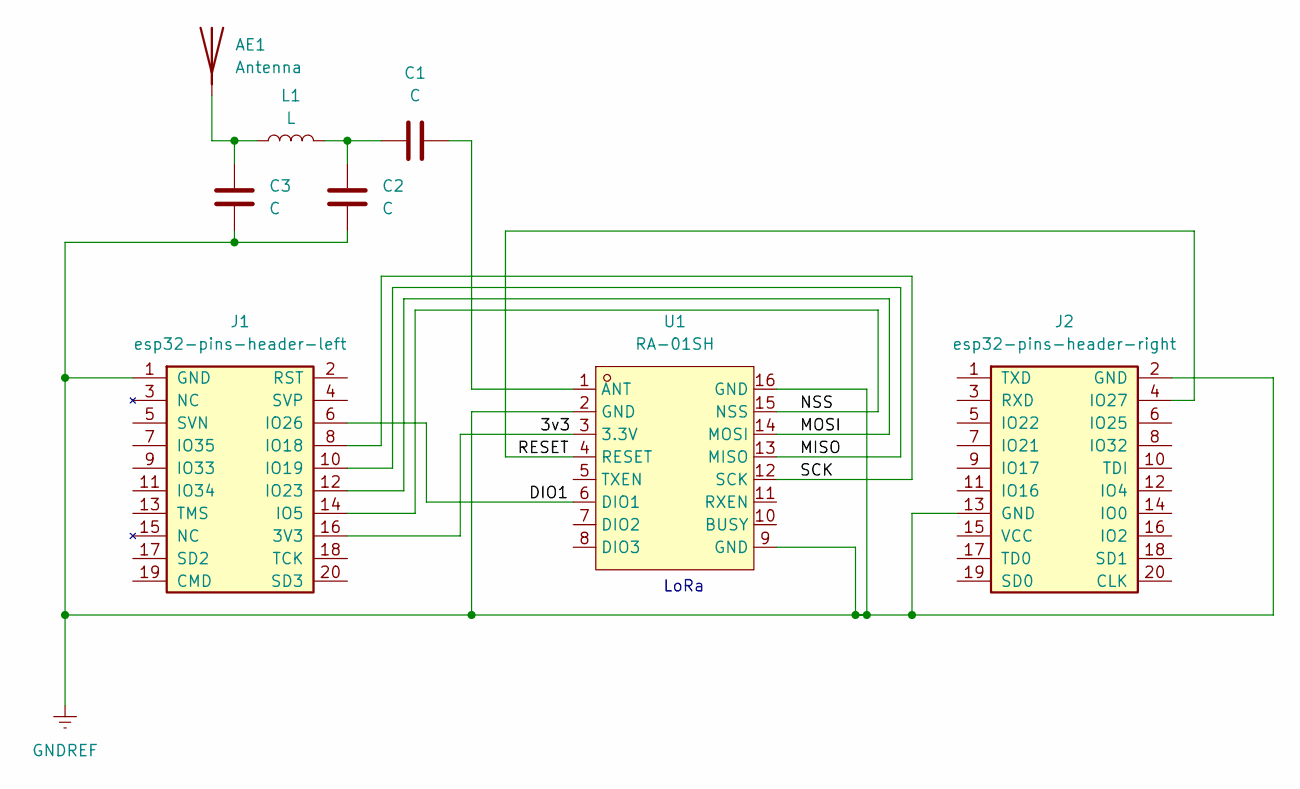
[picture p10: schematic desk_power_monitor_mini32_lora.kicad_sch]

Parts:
AE1: Antenna; Texas_SWRA416_868MHz_915MHz
C1, C2, C3: C; C_0805_2012Metric
J1: esp32-pins-header-left; PinHeader_2x10_P2.54mm_Vertical
J2: esp32-pins-header-right; PinHeader_2x10_P2.54mm_Vertical
L1: L; L_0805_2012Metric
U1: RA-01SH; WIRELM-SMD_RA-01SH; LCSC Part C2764087

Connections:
/3v3: J1.16 (3V3), U1.3 (3.3V)
/DIO1: J1.6 (IO26), U1.6 (DIO1)
/MISO: J1.10 (IO19), U1.13 (MISO)
/MOSI: J1.12 (IO23), U1.14 (MOSI)
/NSS: J1.14 (IO5), U1.15 (NSS)
/RESET: J2.4 (IO27), U1.4 (RESET)
/SCK: J1.8 (IO18), U1.12 (SCK)
GNDREF: C2.2, C3.2, J1.1 (GND), J2.2 (GND), J2.13 (GND), U1.2 (GND), U1.9 (GND), U1.16 (GND)
unnamed: AE1.1 (A), C3.1, L1.1
unnamed: C1.2, C2.1, L1.2
unnamed: C1.1, U1.1 (ANT)

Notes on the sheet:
LoRa

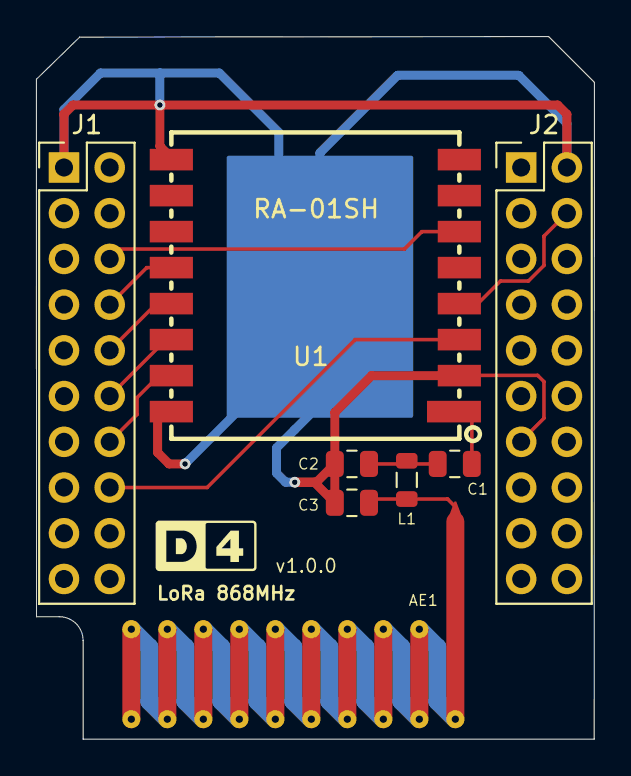
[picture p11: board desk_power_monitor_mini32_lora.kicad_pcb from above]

Board: 2 copper layers, 31.0 x 39.0 mm, 8 parts (0 on the bottom side), 11 nets.

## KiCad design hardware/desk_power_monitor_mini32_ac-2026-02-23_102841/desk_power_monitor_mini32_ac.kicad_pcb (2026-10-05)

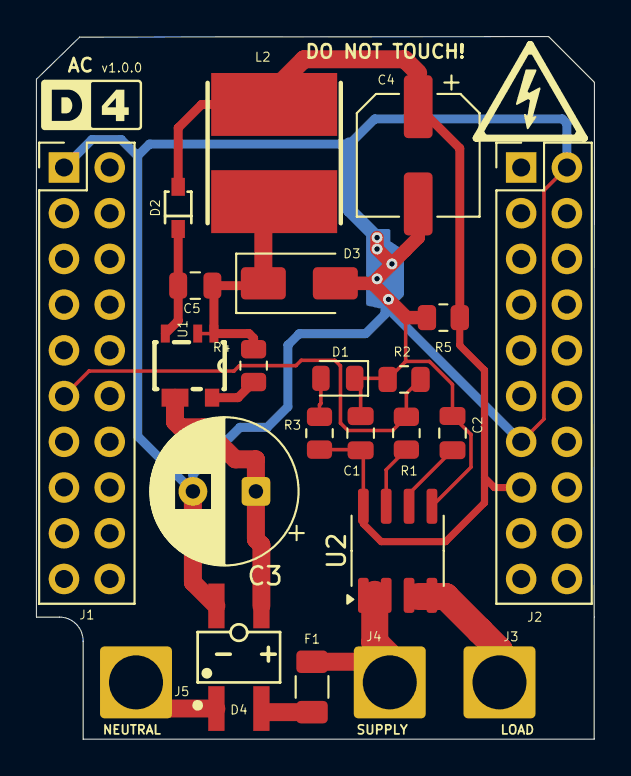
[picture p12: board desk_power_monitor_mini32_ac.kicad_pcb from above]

Board: 2 copper layers, 31.0 x 39.0 mm, 23 parts (0 on the bottom side), 14 nets.

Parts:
C1, C5: 100nF; C_0805_2012Metric
C2: 1nF; C_0805_2012Metric
C3: 4.7µF / 400V electrolytic; CP_Radial_D8.0mm_P3.50mm
C4: 220uF/10V; CP_Elec_6.3x7.7
D1: LED; D_0805_2012Metric
D2: 1N4148WS-C57759; SOD-323_L1.8-W1.3-LS2.5-RD-1
D3: US1M; D_SMA
D4: MB10S(46MIL); MBS_L4.7-W4.0-P2.50-LS7.0-BL
F1: Fuse; Fuse_1206_3216Metric
J1: esp32-pins-header-left; PinHeader_2x10_P2.54mm_Vertical
J2: esp32-pins-header-right; PinHeader_2x10_P2.54mm_Vertical
J3: AC Live OUT; SolderWire-2.5sqmm_1x01_D2.4mm_OD3.6mm
J4: AC Live IN; SolderWire-2.5sqmm_1x01_D2.4mm_OD3.6mm
J5: AC Neutral IN; SolderWire-2.5sqmm_1x01_D2.4mm_OD3.6mm
L2: CY75-220UH; IND-SMD_L7.8-W7.0-A
R1, R2: 10k; R_0805_2012Metric
R3, R5: 1K; R_0805_2012Metric
R4: 0.68R; R_0805_2012Metric
U1: SOT33-5A_L3.9-W2.6-P0.90-BP2525D
U2: ACS712xLCTR-20A; SOIC-8_3.9x4.9mm_P1.27mm

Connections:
GNDREF: C1.1, C2.2, C3.2, C4.2, D1.1 (K), D3.2 (A), D4.4 (-), J1.1 (GND), J2.2 (GND), R2.1, R5.2, U2.5 (GND)
unnamed: D1.2 (A), R3.1
unnamed: C1.2, C4.1, D2.2 (A), J2.15 (VCC), L2.2, R3.2, R5.1, U2.8 (5V)
unnamed: C5.1, D2.1 (C), U1.3 (VCC)
unnamed: C5.2, D3.1 (K), L2.1, R4.2, U1.1 (GND), U1.2 (SEL)
unnamed: C3.1, D4.3 (+), U1.4 (DRAIN)
unnamed: D4.2 (AC), F1.2
unnamed: J1.11 (IO34), R1.2, R2.2
unnamed: J3.1, U2.3 (IP-), U2.4 (IP-)
unnamed: F1.1, J4.1, U2.1 (IP+), U2.2 (IP+)
unnamed: D4.1 (AC), J5.1
unnamed: R4.1, U1.5 (CS)
unnamed: C2.1, U2.6 (FILTER)
unnamed: R1.1, U2.7 (VIOUT)

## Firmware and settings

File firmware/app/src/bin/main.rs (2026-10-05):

//! # Production Current Sensor + LoRaWAN Firmware
//!
//! A `no_std` bare-metal ESP32 binary that measures AC current via ACS712
//! (with voltage divider) and reports it over LoRaWAN as an OTAA Class A
//! device.
//!
//! Behaviour:
//! - Joins the network by OTAA, retrying with backoff until it succeeds
//! - Measures every `sample_interval_s`, accumulating min/avg/max
//! - Transmits an aggregated report every `report_interval_s` (± jitter),
//!   confirmed, retrying once if the network does not acknowledge
//! - Applies configuration downlinks (intervals, jitter, reboot) received in
//!   the receive windows that follow each report, and echoes them back
//! - Persists cumulative mAh, frame counters, join nonce and configuration
//!   across power cycles

#![no_std]
#![no_main]

use app::config::{apply_downlink, DeviceConfig};
use app::flash_storage::WearLevelingStorage;
use app::lora::sx1262::Sx1262;
use app::lora::LoRaDriver;
use app::lorawan::{LoRaWanSession, UplinkOptions};
use app::mac;
use app::packet::{self, SampleAccumulator, FPORT};
use app::session_store::{SessionRecord, SessionStore};

use esp_hal::{
    analog::adc::{Adc, AdcConfig, Attenuation},
    clock::CpuClock,
    gpio::{Input, InputConfig, Level, Output, OutputConfig},
    spi::master::{Config as SpiConfig, Spi},
    time::{Duration, Instant, Rate},
};
use esp_println::println;
use nb::block;

#[panic_handler]
fn panic(info: &core::panic::PanicInfo) -> ! {
    println!("PANIC: {:?}", info);
    loop {
        core::hint::spin_loop();
    }
}

esp_bootloader_esp_idf::esp_app_desc!();

// --- ACS712 Configuration ---

/// Voltage divider ratio: R2 / (R1 + R2) = 10k / (10k + 10k) = 0.5
const DIVIDER_RATIO: f32 = 0.5;

/// ACS712-20A sensitivity in mV/A (before voltage divider)
const SENSITIVITY_MV_PER_A: f32 = 100.0;

/// ESP32 ADC reference voltage in mV (11dB attenuation)
const ADC_REF_MV: f32 = 3300.0;

/// ESP32 12-bit ADC max value
const ADC_MAX: f32 = 4095.0;

/// mV per ADC step
const MV_PER_STEP: f32 = ADC_REF_MV / ADC_MAX;

/// Effective sensitivity at ADC input (after divider)
const EFFECTIVE_SENSITIVITY: f32 = SENSITIVITY_MV_PER_A * DIVIDER_RATIO;

/// Number of samples per 50Hz cycle (20ms)
const SAMPLES_PER_CYCLE: usize = 200;

/// Oversampling count per sample point
const OVERSAMPLE: usize = 64;

/// Number of cycles for calibration
const CALIBRATION_CYCLES: usize = 10;

// --- LoRaWAN identity ---

/// JoinEUI (AppEUI) shared by the fleet.
///
/// All zeros: this is a private network, and we do not own an IEEE-assigned
/// JoinEUI block. The network server matches on DevEUI regardless.
const JOIN_EUI: [u8; 8] = [0; 8];

// --- Timing ---

/// How long to wait after a failed join before trying again, and the ceiling
/// that backoff grows to. Keeps a device that cannot reach a gateway from
/// saturating the band.
const JOIN_RETRY_BASE_MS: u64 = 10_000;
const JOIN_RETRY_MAX_MS: u64 = 300_000;

/// Cumulative energy is checkpointed on this cadence; the session record is
/// written on every uplink instead, because a stale frame counter gets frames
/// rejected by the network server.
const SAVE_INTERVAL_MS: u64 = 5 * 60 * 1_000;

/// Serial energy log cadence.
const ENERGY_LOG_MS: u64 = 5 * 60 * 1_000;

/// Floor on time between transmissions, whatever the configured interval.
const MIN_TX_INTERVAL_MS: u64 = 5_000;

/// Consecutive unacknowledged reports before the session is abandoned.
///
/// Reports are confirmed, so silence this sustained means the network has
/// stopped answering — the server forgot the session, or was replaced. Without
/// this the device would transmit into the void indefinitely, since nothing
/// can reach a device whose keys the network no longer holds.
const UNACKED_REPORTS_BEFORE_REJOIN: u8 = 4;

// --- MAC address reading ---

fn get_mac_address() -> [u8; 6] {
    let mac_ptr = 0x3FF5_A004 as *const u32;
    let mac_ptr2 = 0x3FF5_A008 as *const u32;

    unsafe {
        let word0 = core::ptr::read_volatile(mac_ptr);
        let word1 = core::ptr::read_volatile(mac_ptr2);

        [
            (word1 >> 8) as u8,
            word1 as u8,
            (word0 >> 24) as u8,
            (word0 >> 16) as u8,
            (word0 >> 8) as u8,
            word0 as u8,
        ]
    }
}

/// Expand a MAC-48 into an EUI-64 the usual way: OUI, `FF FE`, then the rest.
fn dev_eui_from_mac(mac: &[u8; 6]) -> [u8; 8] {
    [
        mac[0], mac[1], mac[2], 0xFF, 0xFE, mac[3], mac[4], mac[5],
    ]
}

/// AppKey is the DevEUI repeated, following the convention Milesight uses for
/// its own sensors. It means a device can be onboarded from nothing but the
/// join request it puts on air.
fn app_key_from_dev_eui(dev_eui: &[u8; 8]) -> [u8; 16] {
    let mut key = [0u8; 16];
    key[..8].copy_from_slice(dev_eui);
    key[8..].copy_from_slice(dev_eui);
    key
}

/// Simple deterministic PRNG (xorshift32) seeded from MAC.
///
/// Used only for transmit jitter. It must not be used for the join nonce,
/// which is persisted and monotonic — this PRNG produces the same sequence
/// after every reset.
struct Rng {
    state: u32,
}

impl Rng {
    fn from_mac(mac: &[u8; 6]) -> Self {
        let mut seed: u32 = 0x1234_5678;
        for (i, &b) in mac.iter().enumerate() {
            seed ^= (b as u32) << ((i % 4) * 8);
        }
        if seed == 0 {
            seed = 0xDEAD_BEEF;
        }
        Self { state: seed }
    }

    fn next(&mut self) -> u32 {
        let mut x = self.state;
        x ^= x << 13;
        x ^= x >> 17;
        x ^= x << 5;
        self.state = x;
        x
    }

    /// Random value in range [0, max)
    fn next_range(&mut self, max: u64) -> u64 {
        if max == 0 {
            return 0;
        }
        (self.next() as u64) % max
    }
}

fn delay_ms(ms: u64) {
    let start = Instant::now();
    while start.elapsed() < Duration::from_millis(ms) {}
}

/// Milliseconds until the next report, given the configured interval and jitter.
fn next_report_delay_ms(config: &DeviceConfig, rng: &mut Rng) -> u64 {
    let base = config.report_interval_s as u64 * 1000;
    if config.jitter_s == 0 {
        return base;
    }
    let spread = config.jitter_s as u64 * 1000;
    // Centred on the configured interval: base ± jitter, never below the floor.
    let offset = rng.next_range(spread * 2);
    (base + offset)
        .saturating_sub(spread)
        .max(MIN_TX_INTERVAL_MS)
}

#[esp_hal::main]
fn main() -> ! {
    let hal_config = esp_hal::Config::default().with_cpu_clock(CpuClock::max());
    let peripherals = esp_hal::init(hal_config);

    println!(
        "\n{{\"event\":\"boot\",\"firmware\":\"current_lora_otaa\",\"version\":\"{}\"}}",
        env!("CARGO_PKG_VERSION")
    );

    // 1. Identity
    let mac = get_mac_address();
    let dev_eui = dev_eui_from_mac(&mac);
    let app_key = app_key_from_dev_eui(&dev_eui);
    println!(
        "{{\"event\":\"identity\",\"mac\":\"{:02X}{:02X}{:02X}{:02X}{:02X}{:02X}\",\"dev_eui\":\"{:02X}{:02X}{:02X}{:02X}{:02X}{:02X}{:02X}{:02X}\"}}",
        mac[0], mac[1], mac[2], mac[3], mac[4], mac[5],
        dev_eui[0], dev_eui[1], dev_eui[2], dev_eui[3],
        dev_eui[4], dev_eui[5], dev_eui[6], dev_eui[7]
    );

    let mut rng = Rng::from_mac(&mac);

    // 2. Persistent state
    let mut flash_storage = WearLevelingStorage::new();
    let (mut cumulative_uah, _legacy_fcnt) = flash_storage.load();

    let mut session_store = SessionStore::new();
    let record = session_store.load();
    let mut config = record.config;

    println!(
        "{{\"event\":\"config_loaded\",\"report_s\":{},\"jitter_s\":{},\"sample_s\":{},\"cumulative_mah\":{:.3}}}",
        config.report_interval_s,
        config.jitter_s,
        config.sample_interval_s,
        cumulative_uah as f64 / 1000.0
    );

    // 3. Init LoRa FIRST — the radio powering up affects the ADC baseline
    let rst = Output::new(peripherals.GPIO27, Level::High, OutputConfig::default());
    let nss = Output::new(peripherals.GPIO5, Level::High, OutputConfig::default());
    let busy = Input::new(peripherals.GPIO26, InputConfig::default());

    let spi_config = SpiConfig::default().with_frequency(Rate::from_mhz(1));
    let spi = Spi::new(peripherals.SPI2, spi_config)
        .unwrap()
        .with_sck(peripherals.GPIO18)
        .with_miso(peripherals.GPIO19)
        .with_mosi(peripherals.GPIO23);

    let mut lora = Sx1262::new(spi, nss, rst, busy);
    let lora_status = lora.init();

    if lora_status.detected {
        println!(
            "{{\"event\":\"lora_init\",\"status\":\"ok\",\"freq_mhz\":{:.1}}}",
            lora_status.frequency_mhz
        );
    } else {
        println!(
            "{{\"event\":\"lora_init\",\"status\":\"error\",\"version\":\"0x{:02x}\"}}",
            lora_status.version
        );
    }

    let mut session = LoRaWanSession::new(dev_eui, JOIN_EUI, app_key, record.dev_nonce);
    record.apply_to(&mut session);
    if session.joined {
        println!(
            "{{\"event\":\"session_restored\",\"dev_addr\":\"{:02X}{:02X}{:02X}{:02X}\",\"fcnt_up\":{}}}",
            session.dev_addr[3], session.dev_addr[2], session.dev_addr[1], session.dev_addr[0],
            session.fcnt_up
        );
    }

    // 4. Status LED on GPIO2
    let mut led = Output::new(peripherals.GPIO2, Level::Low, OutputConfig::default());

    // 5. ADC on GPIO34 (ACS712 via voltage divider)
    let mut adc_config = AdcConfig::new();
    let mut adc_pin = adc_config.enable_pin(peripherals.GPIO34, Attenuation::_11dB);
    let mut adc = Adc::new(peripherals.ADC1, adc_config);

    // Capture one 50Hz cycle (20ms) of oversampled ADC readings
    macro_rules! capture_cycle {
        ($adc:expr, $pin:expr, $samples:expr) => {{
            let capture_start = Instant::now();
            for i in 0..SAMPLES_PER_CYCLE {
                let target_us = (i as u64 * 20_000) / SAMPLES_PER_CYCLE as u64;
                let mut sum: u32 = 0;
                for _ in 0..OVERSAMPLE {
                    let raw: u16 = block!($adc.read_oneshot($pin)).unwrap_or(0);
                    sum += raw as u32;
                }
                $samples[i] = (sum / OVERSAMPLE as u32) as u16;
                let target_time = capture_start + Duration::from_micros(target_us);
                while Instant::now() < target_time {}
            }
        }};
    }

    // 6. Calibrate DC offset (no load) — LoRa is already initialised
    let mut dc_offset: f32 = 0.0;
    let mut cal_samples: [u16; SAMPLES_PER_CYCLE] = [0; SAMPLES_PER_CYCLE];
    for _ in 0..CALIBRATION_CYCLES {
        capture_cycle!(adc, &mut adc_pin, cal_samples);
        let mut sum: u32 = 0;
        for &s in cal_samples.iter() {
            sum += s as u32;
        }
        dc_offset += sum as f32 / SAMPLES_PER_CYCLE as f32;
    }
    dc_offset /= CALIBRATION_CYCLES as f32;
    println!(
        "{{\"event\":\"calibrated\",\"dc_offset_adc\":{:.1},\"dc_offset_mv\":{:.1}}}",
        dc_offset,
        dc_offset * MV_PER_STEP
    );

    // --- Main loop state ---
    let mut samples: [u16; SAMPLES_PER_CYCLE] = [0; SAMPLES_PER_CYCLE];
    let mut accumulator = SampleAccumulator::new();
    let mut iteration: u32 = 0;
    let mut tx_count: u32 = 0;

    let mut last_sample_time = Instant::now();
    let mut last_report_time = Instant::now();
    let mut last_save_time = Instant::now();
    let mut last_energy_log = Instant::now();
    let mut join_backoff_ms = JOIN_RETRY_BASE_MS;
    let mut unacked_reports: u8 = 0;
    let mut last_join_attempt: Option<Instant> = None;
    let mut send_device_info = false;

    // The first report goes out promptly so a freshly powered device is
    // visible without waiting out a full interval.
    let mut report_delay_ms = MIN_TX_INTERVAL_MS;

    println!("{{\"event\":\"ready\"}}");

    loop {
        iteration += 1;

        // --- Join, if we are not on the network ---
        if !session.joined {
            let due = match last_join_attempt {
                None => true,
                Some(previous) => previous.elapsed() >= Duration::from_millis(join_backoff_ms),
            };

            if due && lora_status.detected {
                last_join_attempt = Some(Instant::now());

                // The nonce is spent the moment the request goes on air, so it
                // is incremented and persisted before transmitting. Reusing one
                // gets the join dropped without explanation.
                session.dev_nonce = session.dev_nonce.wrapping_add(1);
                session_store.save(&SessionRecord::from_session(&session, &config));

                if mac::join(&mut lora, &mut session) {
                    join_backoff_ms = JOIN_RETRY_BASE_MS;
                    send_device_info = true;
                    report_delay_ms = MIN_TX_INTERVAL_MS;
                    last_report_time = Instant::now();
                    session_store.save(&SessionRecord::from_session(&session, &config));
                } else {
                    join_backoff_ms = (join_backoff_ms * 2).min(JOIN_RETRY_MAX_MS);
                }
            }

            // Nothing else is meaningful before we have a session.
            blink(&mut led, 10);
            delay_ms(500);
            continue;
        }

        // --- Sample ---
        let sample_due =
            last_sample_time.elapsed() >= Duration::from_secs(config.sample_interval_s as u64);

        if sample_due {
            capture_cycle!(adc, &mut adc_pin, samples);

            let mut sum: u32 = 0;
            let mut min_val = u16::MAX;
            let mut max_val = 0u16;
            for &s in samples.iter() {
                sum += s as u32;
                if s < min_val {
                    min_val = s;
                }
                if s > max_val {
                    max_val = s;
                }
            }
            let cycle_offset = sum as f32 / SAMPLES_PER_CYCLE as f32;

            let mut sum_sq: f32 = 0.0;
            for &s in samples.iter() {
                let diff = (s as f32 - cycle_offset) * MV_PER_STEP;
                sum_sq += diff * diff;
            }
            let rms_mv = libm::sqrtf(sum_sq / SAMPLES_PER_CYCLE as f32);
            let current_ma = ((rms_mv / EFFECTIVE_SENSITIVITY) * 1000.0) as u16;

            accumulator.push(current_ma);

            // Integrate energy over the interval this sample represents.
            let dt_ms = last_sample_time.elapsed().as_millis() as u64;
            last_sample_time = Instant::now();
            cumulative_uah = cumulative_uah.saturating_add((current_ma as u64 * dt_ms) / 3600);

            println!(
                "[{}] {} mA | samples={} | cumulative={:.3} mAh",
                iteration,
                current_ma,
                accumulator.count(),
                cumulative_uah as f64 / 1000.0
            );

            // A saturated or dead ADC is worth surfacing on the LED, since the
            // reported current would otherwise look plausible.
            if min_val >= 4095 || max_val == 0 {
                for _ in 0..3 {
                    blink(&mut led, 50);
                    delay_ms(50);
                }
            } else {
                blink(&mut led, 10);
            }
        }

        // --- Checkpoint cumulative energy ---
        if last_save_time.elapsed() >= Duration::from_millis(SAVE_INTERVAL_MS) {
            last_save_time = Instant::now();
            flash_storage.save(cumulative_uah, session.fcnt_up);
        }

        if last_energy_log.elapsed() >= Duration::from_millis(ENERGY_LOG_MS) {
            last_energy_log = Instant::now();
            println!(
                "{{\"event\":\"energy\",\"cumulative_uah\":{},\"mah\":{:.3}}}",
                cumulative_uah,
                cumulative_uah as f64 / 1000.0
            );
        }

        // --- Report ---
        let report_due = last_report_time.elapsed() >= Duration::from_millis(report_delay_ms);
        if report_due && lora_status.detected {
            let payload = if send_device_info {
                packet::build_device_info(&session.dev_eui)
            } else {
                let cumulative_mah = (cumulative_uah / 1000).min(u32::MAX as u64) as u32;
                packet::build_report(&accumulator.summarise(cumulative_mah))
            };

            let opts = UplinkOptions {
                confirmed: true,
                ack: false,
            };

            let mut downlink_buf = [0u8; 128];
            let mut result = mac::send_uplink(
                &mut lora,
                &mut session,
                opts,
                FPORT,
                payload.as_bytes(),
                &mut downlink_buf,
            );

            // Confirmed uplinks are retried exactly once when unacknowledged,
            // reusing the same frame counter — that is what makes it a
            // retransmission rather than a new frame.
            let acknowledged = result.downlink.map_or(false, |d| d.ack);
            if result.transmitted && !acknowledged {
                println!("{{\"event\":\"uplink_unacked\",\"fcnt\":{}}}", session.fcnt_up);
                delay_ms(1000);
                result = mac::send_uplink(
                    &mut lora,
                    &mut session,
                    opts,
                    FPORT,
                    payload.as_bytes(),
                    &mut downlink_buf,
                );
            }

            tx_count += 1;
            println!(
                "{{\"event\":\"tx\",\"seq\":{},\"kind\":\"{}\",\"ok\":{},\"fcnt\":{},\"len\":{},\"acked\":{},\"rx_delay_s\":{},\"rx2_dr\":{}}}",
                tx_count,
                if send_device_info { "device_info" } else { "report" },
                result.transmitted,
                session.fcnt_up,
                payload.len(),
                result.downlink.map_or(false, |d| d.ack),
                session.rx_delay_s,
                session.rx2_dr
            );

            if result.transmitted {
                // The frame is done with, acknowledged or not; the next one
                // must not reuse this counter.
                session.fcnt_up = session.fcnt_up.wrapping_add(1);

                if send_device_info {
                    send_device_info = false;
                } else {
                    accumulator.reset();
                }
            }

            if result.downlink.is_some() {
                unacked_reports = 0;
            } else if result.transmitted {
                unacked_reports = unacked_reports.saturating_add(1);
                if unacked_reports >= UNACKED_REPORTS_BEFORE_REJOIN {
                    println!(
                        "{{\"event\":\"rejoin\",\"reason\":\"unacked\",\"count\":{}}}",
                        unacked_reports
                    );
                    unacked_reports = 0;
                    session.joined = false;
                    last_join_attempt = None;
                    join_backoff_ms = JOIN_RETRY_BASE_MS;
                    session_store.save(&SessionRecord::from_session(&session, &config));
                    continue;
                }
            }

            // --- Downlink commands ---
            let mut reboot_requested = false;
            if let Some(downlink) = result.downlink {
                if downlink.len > 0 && downlink.port == FPORT {
                    let outcome = apply_downlink(&mut config, &downlink_buf[..downlink.len]);
                    println!(
                        "{{\"event\":\"downlink\",\"port\":{},\"len\":{},\"accepted\":{},\"malformed\":{},\"report_s\":{},\"jitter_s\":{},\"sample_s\":{}}}",
                        downlink.port,
                        downlink.len,
                        outcome.accepted,
                        outcome.malformed,
                        config.report_interval_s,
                        config.jitter_s,
                        config.sample_interval_s
                    );

                    reboot_requested = outcome.reboot;

                    // Echo what was applied. This is the only acknowledgement
                    // the operator gets that a command landed, so it goes out
                    // before anything else — including a reboot.
                    if !outcome.echo.is_empty() {
                        session_store.save(&SessionRecord::from_session(&session, &config));
                        let echo_result = mac::send_uplink(
                            &mut lora,
                            &mut session,
                            UplinkOptions {
                                confirmed: false,
                                ack: true,
                            },
                            FPORT,
                            outcome.echo.as_bytes(),
                            &mut [0u8; 128],
                        );
                        if echo_result.transmitted {
                            session.fcnt_up = session.fcnt_up.wrapping_add(1);
                        }
                    }
                } else if downlink.len > 0 {
                    println!(
                        "{{\"event\":\"downlink_ignored\",\"port\":{},\"len\":{}}}",
                        downlink.port, downlink.len
                    );
                }
            }

            // Persist counters and any config change before scheduling the
            // next report, so a reset here cannot replay a frame counter.
            flash_storage.save(cumulative_uah, session.fcnt_up);
            session_store.save(&SessionRecord::from_session(&session, &config));

            if reboot_requested {
                println!("{{\"event\":\"reboot\",\"reason\":\"downlink\"}}");
                delay_ms(100);
                esp_hal::system::software_reset();
            }

            last_report_time = Instant::now();
            report_delay_ms = next_report_delay_ms(&config, &mut rng);
        }
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

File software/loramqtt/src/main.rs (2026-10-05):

//! Minimal MQTT broker for a Milesight LoRaWAN gateway.
//!
//! Prints and decodes uplinks the gateway forwards, and routes published
//! messages to whoever has subscribed. That routing is what makes downlinks
//! possible: the gateway subscribes to its configured downlink topic, and
//! anything published there — with `mosquitto_pub`, say — is delivered to it
//! and queued for the device's next receive window.
//!
//! Speaks enough of MQTT 3.1.1 and 5.0 for that job and no more: QoS 0
//! delivery, no retained messages, no persistent sessions.

use base64::{engine::general_purpose::STANDARD as BASE64, Engine};
use milesight_d4::tlv;
use std::collections::HashMap;
use std::io::{Read, Write};
use std::net::{TcpListener, TcpStream};
use std::sync::atomic::{AtomicUsize, Ordering};
use std::sync::{Arc, Mutex};
use std::thread;

// MQTT packet types (upper 4 bits of first byte)
const CONNECT: u8 = 1;
const CONNACK: u8 = 2;
const PUBLISH: u8 = 3;
const PUBACK: u8 = 4;
const SUBSCRIBE: u8 = 8;
const SUBACK: u8 = 9;
const PINGREQ: u8 = 12;
const PINGRESP: u8 = 13;
const DISCONNECT: u8 = 14;

fn decode_remaining_length(stream: &mut TcpStream) -> std::io::Result<usize> {
    let mut multiplier: usize = 1;
    let mut value: usize = 0;
    let mut buf = [0u8; 1];
    loop {
        stream.read_exact(&mut buf)?;
        value += (buf[0] & 0x7F) as usize * multiplier;
        if buf[0] & 0x80 == 0 {
            break;
        }
        multiplier *= 128;
        if multiplier > 128 * 128 * 128 {
            return Err(std::io::Error::new(
                std::io::ErrorKind::InvalidData,
                "malformed remaining length",
            ));
        }
    }
    Ok(value)
}

fn encode_remaining_length(mut len: usize) -> Vec<u8> {
    let mut out = Vec::new();
    loop {
        let mut byte = (len % 128) as u8;
        len /= 128;
        if len > 0 {
            byte |= 0x80;
        }
        out.push(byte);
        if len == 0 {
            break;
        }
    }
    out
}

fn read_utf8_string(data: &[u8], offset: &mut usize) -> String {
    if *offset + 2 > data.len() {
        return String::new();
    }
    let len = ((data[*offset] as usize) << 8) | data[*offset + 1] as usize;
    *offset += 2;
    if *offset + len > data.len() {
        return String::new();
    }
    let s = String::from_utf8_lossy(&data[*offset..*offset + len]).to_string();
    *offset += len;
    s
}

fn send_packet(stream: &mut TcpStream, ptype: u8, flags: u8, payload: &[u8]) -> std::io::Result<()> {
    let header_byte = (ptype << 4) | (flags & 0x0F);
    let mut packet = vec![header_byte];
    packet.extend(encode_remaining_length(payload.len()));
    packet.extend_from_slice(payload);
    stream.write_all(&packet)
}

/// Decode an uplink payload with the shared TLV decoder.
fn decode_uplink_payload(bytes: &[u8], json: &serde_json::Value) {
    let decoded = tlv::decode(bytes);
    if decoded.fields.is_empty() {
        return;
    }
    let device_name = json
        .get("deviceName")
        .and_then(|v| v.as_str())
        .or_else(|| json.get("devEUI").and_then(|v| v.as_str()))
        .unwrap_or("?");
    println!("[d4] {} | {}", device_name, decoded.summary());
    if let Some(offset) = decoded.undecoded_at {
        println!("[d4] {} | stopped decoding at byte {}", device_name, offset);
    }
}

/// Connected clients, so a publish can be routed to its subscribers.
#[derive(Default)]
struct Broker {
    clients: Mutex<HashMap<usize, Client>>,
}

struct Client {
    peer: String,
    stream: TcpStream,
    subscriptions: Vec<String>,
}

impl Broker {
    fn add(&self, id: usize, peer: String, stream: TcpStream) {
        self.clients.lock().unwrap().insert(
            id,
            Client {
                peer,
                stream,
                subscriptions: Vec::new(),
            },
        );
    }

    fn remove(&self, id: usize) {
        self.clients.lock().unwrap().remove(&id);
    }

    fn subscribe(&self, id: usize, filter: String) {
        if let Some(client) = self.clients.lock().unwrap().get_mut(&id) {
            client.subscriptions.push(filter);
        }
    }

    /// Deliver a message to every subscriber whose filter matches.
    ///
    /// Delivered at QoS 0 regardless of what the subscriber asked for: the
    /// gateway re-queues downlinks itself, so there is nothing useful for this
    /// broker to add by tracking acknowledgements.
    fn route(&self, topic: &str, payload: &[u8], from: usize) {
        let mut clients = self.clients.lock().unwrap();
        for (id, client) in clients.iter_mut() {
            if *id == from {
                continue;
            }
            if !client.subscriptions.iter().any(|f| topic_matches(f, topic)) {
                continue;
            }
            let mut packet = Vec::new();
            packet.extend_from_slice(&(topic.len() as u16).to_be_bytes());
            packet.extend_from_slice(topic.as_bytes());
            packet.extend_from_slice(payload);
            match send_packet(&mut client.stream, PUBLISH, 0, &packet) {
                Ok(()) => println!(
                    "[mqtt] delivered {} bytes on {} to {}",
                    payload.len(),
                    topic,
                    client.peer
                ),
                Err(e) => println!("[mqtt] delivery to {} failed: {}", client.peer, e),
            }
        }
    }
}

/// MQTT topic filter matching, including `+` and `#` wildcards.
fn topic_matches(filter: &str, topic: &str) -> bool {
    let mut f = filter.split('/');
    let mut t = topic.split('/');

    loop {
        match (f.next(), t.next()) {
            (Some("#"), _) => return true,
            (Some("+"), Some(_)) => continue,
            (Some(a), Some(b)) if a == b => continue,
            (None, None) => return true,
            _ => return false,
        }
    }
}
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
